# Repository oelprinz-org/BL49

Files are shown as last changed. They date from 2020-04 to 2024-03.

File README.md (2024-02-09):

# BL49

Wideband Lambda Controller with Bosch CJ125 and LSU 4.9 with 0-5V output and CAN-Bus Interface

Feature list

- CAN output, compatible with AEM X-Series UEGO
- analog output for lambda 0.65 to 1.3 (0.25v to 4.8V)
- debug messages over CAN (pid, heater status, diag registers, ...)
- activatable via TTL input (INPUT 1)
- fast: 10ms refresh rate (reading the probe, calculation lambda and O2, sending CAN message and setting analog output)
- Bosch recommended heating strategy

## 04.01.2023 - Current status of firmware development

- analog output for lambda 0.65 to 1.3 (0.25v to 4.8V): done
- CAN output (AEM X-Series UEGO protocol): done
- debug messages over CAN: done
- Bosch recommended heating strategy: done
- PID controller for heating the probe: done
- activation per GPIO (pull **IN1** to GND): done
- <del>activation per CAN: open</del>

## 29.04.2020 - Version 0.0.1 - only hardware released / no software available at the moment  

Interactive BOM for easier hand-soldering you can download from the github (BL49/hardware/V0.0.1/bom)  
or access online here: <https://oelprinz.000webhostapp.com/BL49/V0.0.1/iBOM/ibom.html>  
Quick link to schematic: <https://github.com/oelprinz-org/BL49/blob/master/hardware/V0.0.1/schematics.pdf>  

## Bosch CJ125 (LQFP32 package) part numbers

|Bosch part number|
|:----------------|
|30615|
|40103|
|30522|

### Suitable Bosch lambda probes

Basically, the Bosch probes whose numbers start with **0 258 017** will fit, also Bosch **0 281 004**.  
Bosch numbers beginning with **0 258 007** are *LSU 4.2* probes and will not fit.

|Bosch number  |Length overall|Comment|
|---|---|---|
|0 258 017 012 |1060mm||
|0 258 017 025 |1000mm|Bosch motorsport part, **tested during development**|
|0 281 004 028 |540mm|common probe for diesel engines, **Used during development**|
|0 258 017 029 |620mm|grey, used by BMW after 09/2006 (1178 7539124)|
|0 258 017 038 |340mm|grey, used by BMW (11787537984)|
|0 258 017 092 |950mm|black, used by BMW (1178 7540167)|
|0 258 017 126 |680mm|black, used by BMW after 09/2006 (1178 7561410)|
|0 281 004 150 |1215mm||
|0 281 004 184 |1000mm||
|...|||

### LSU4.9 probe pinout

|Pin#|Color|Description|Symbol|
|----|-----|---|---|
|1|red|Pump current APE|IP|
|2|yellow|Virtual ground IPN|VM|
|3|white|Heater voltage H-|Uh-|
|4|grey|Heater voltaget H+|Uh+|
|5|green|Trim Resistor RT|IA|
|6|black|Nernst voltage UN|RE|

### Hardware

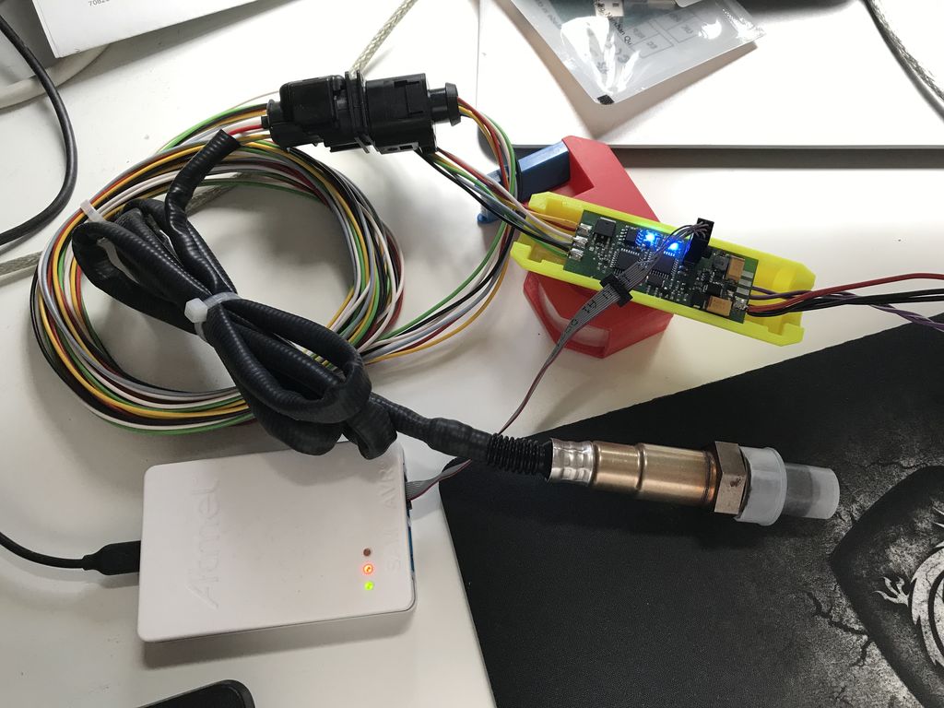
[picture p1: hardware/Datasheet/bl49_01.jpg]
Hardware


### MCU Fuses

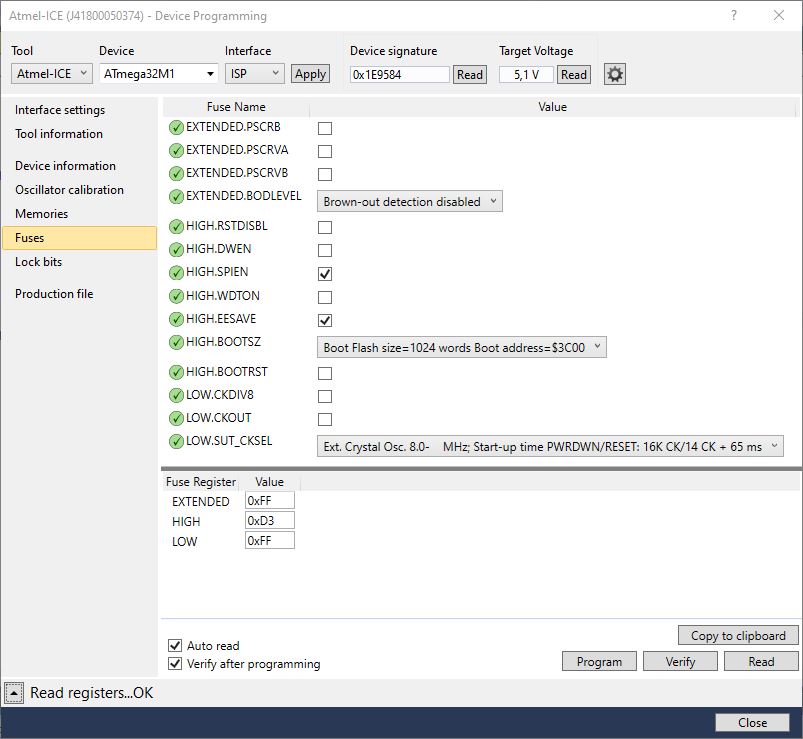
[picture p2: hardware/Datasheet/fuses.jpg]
Fuses


### AEM X-Series CAN layout

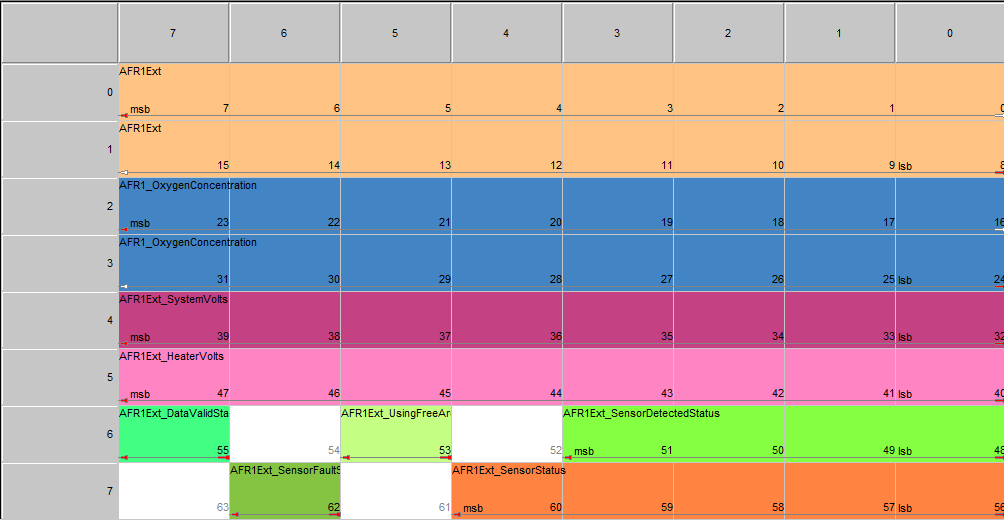
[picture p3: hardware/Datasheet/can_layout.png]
AEM X-Series CAN layout


### Assembled Prototype

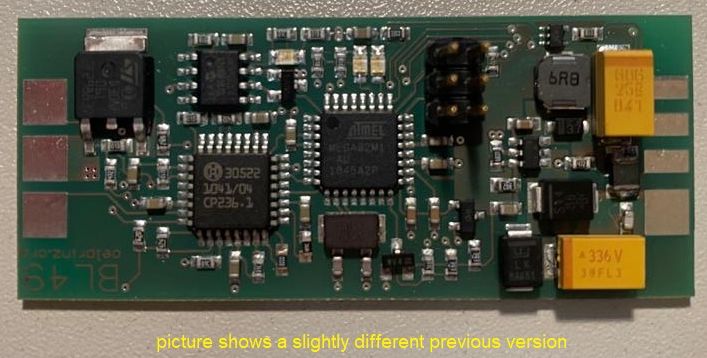
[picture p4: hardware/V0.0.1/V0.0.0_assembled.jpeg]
Assembled Prototype


### PCB Layout

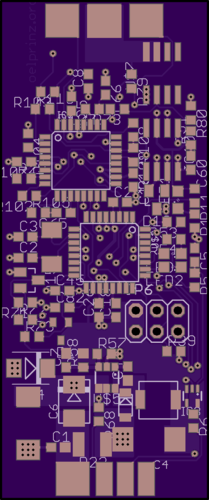
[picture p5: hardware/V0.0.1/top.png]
Top Side

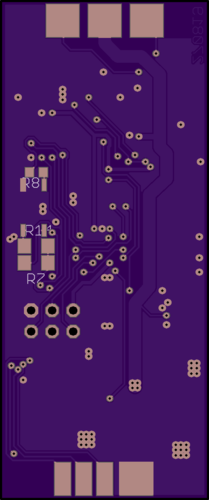
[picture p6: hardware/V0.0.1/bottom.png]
Bottom

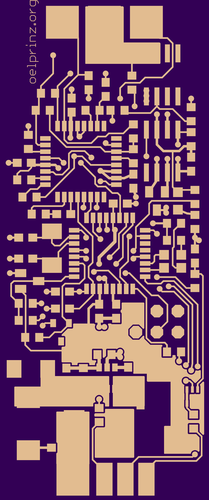
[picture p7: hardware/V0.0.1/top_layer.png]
Top Layer

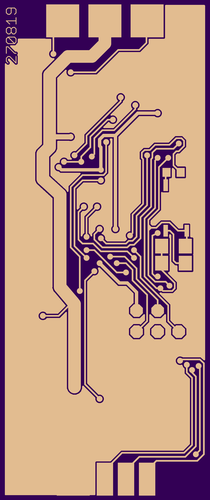
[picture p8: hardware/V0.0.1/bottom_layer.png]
Bottom Layer


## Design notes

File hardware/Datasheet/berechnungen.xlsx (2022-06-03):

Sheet: PWM
Fcpu | 16000000
Prescaler | 256 | 1, 8, 64, 256 and 1024 are valid
Resolution, bit | 8
TOP | 255
Fpwm | 244.140625
Ubat, V | 13.6
condens, V | 1.5
duty, % | 11.02941176
dutyCycle | 112.9411765

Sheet: Ip
Shunt | 61900
Amp | 8
Ua | 2069
Ua_ref | 1503
delta | 566000
divisor | 495200
Ip | 1142.972536

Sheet: ADC
Referenz, V | 5
ADC Wert | 563 | 566
ADC-Spannung, V | 2.749023438
Reihenwiderstand | 40000
Massenwiderstand | 10000
Spannungsteiler | 5 | Gesamtwiderstand / Massenwiderstand
echte Spannung, V | 13.74511719
echte Spannung, V | 13
ADC-Spannung, V | 2.6
ADC-Wert | 532.48
ADC Wert für Referenz | 247
Spannung | 1.206054688
Differenz | -0.0189453125
ADC Ua | 135 | 0.6591796875
ADC Ur | 299 | 1.459960938
Ua bereinigt | 0.678125
Ur bereinigt | 1.47890625
Spannung Referenz, mV | 1225
ADC Wert dazu: | 251 | 1225.585938
Spannung Referenz gemessen | 247
Drift: | 978
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

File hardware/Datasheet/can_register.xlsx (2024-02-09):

CANPAGE
MOBNB3 | MOBNB2 | MOBNB1 | MOBNB0 | AINC | INDX2 | INDX1 | INDX0 | HexWert
0 | 0 | 0 | 1 | 0 | 0 | 0 | 1 | 11
CANGSTA
- | OVRG | - | TXBSY | RXBSY | ENFG | BOFF | ERRP | HexWert
 | 0 |  | 0 | 0 | 0 | 0 | 0
CANSTMOB
DLCW | TXOK | RXOK | BERR | SERR | CERR | FERR | AERR | HexWert
0 | 0 | 0 | 0 | 0 | 0 | 0 | 0 | 0
CANGIT
CANIT | BOFFIT | OVRTIM | BXOK | SERG | CERG | FERG | AERG | HexWert
1 | 0 | 1 | 0 | 0 | 0 | 0 | 0 | a0
CANCDMOB
CONMOB1 | CONMOB0 | RPLV | IDE | DLC3 | DLC2 | DLC1 | DLC0 | HexWert
0 | 1 | 0 | 1 | 0 | 0 | 1 | 0 | 52

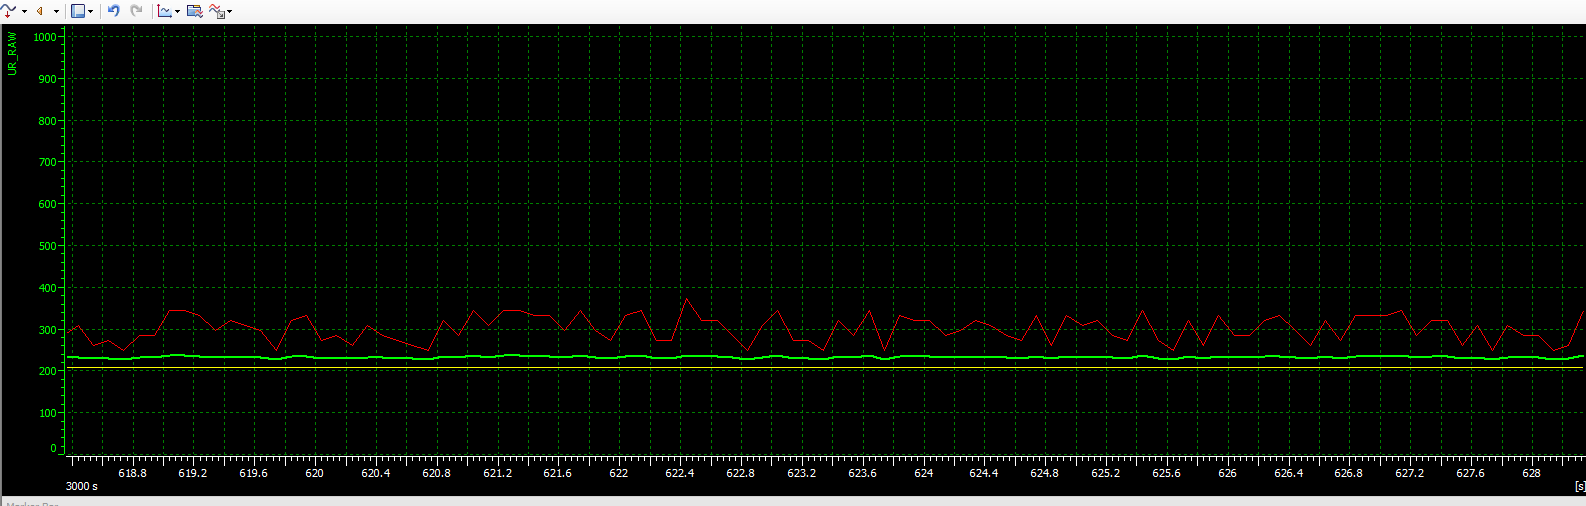
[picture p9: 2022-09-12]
hardware/Datasheet/PID.png

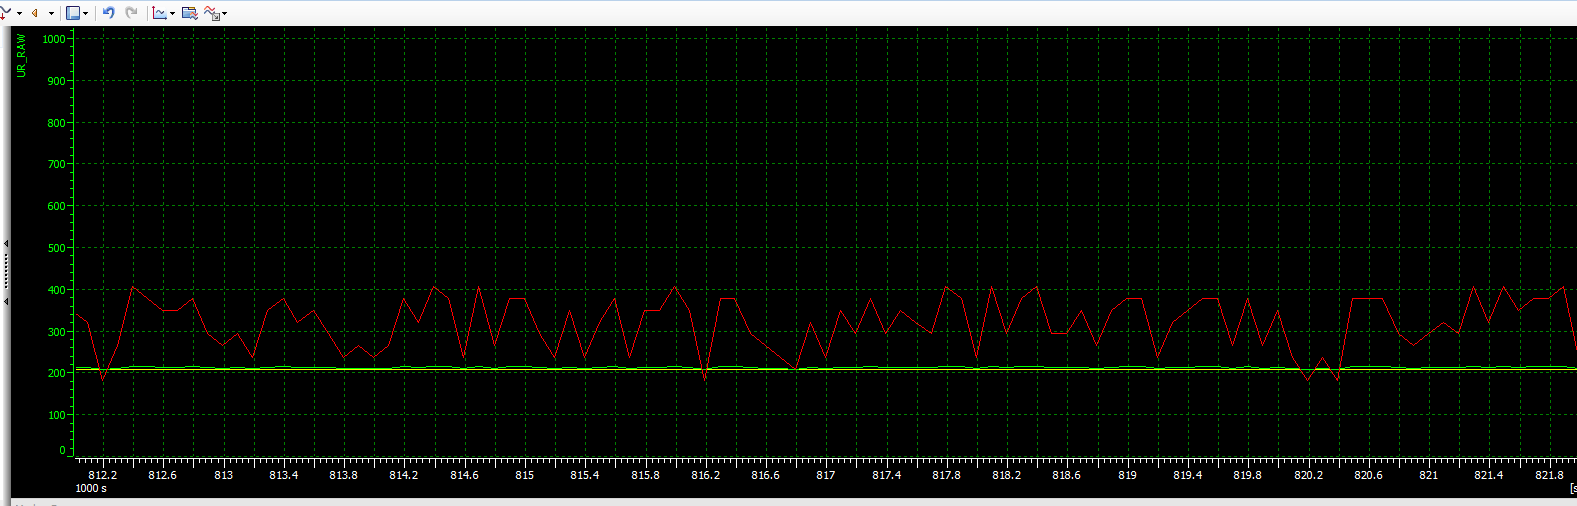
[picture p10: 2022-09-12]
hardware/Datasheet/PID_2.png

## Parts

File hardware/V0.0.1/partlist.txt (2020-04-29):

Qty Value                Device              Package       Parts                                            Description                                                              MF MPN            OC_FARNELL OC_NEWARK
3   100k                 R-EU_R0603          R0603         R80, R107, R108                                  RESISTOR, European symbol                                                                                      
10  100n                 C-EUC0603           C0603         C7, C16, C18, C22, C25, C26, C60, C65, C66, C107 CAPACITOR, European symbol                                                                                     
1   100nF                C-EUC0603           C0603         C5                                               CAPACITOR, European symbol                                                                                     
1   100r                 R-EU_R1206          R1206         R7                                               RESISTOR, European symbol                                                                                      
4   10k                  R-EU_R0603          R0603         R11, R29, R71, R104                              RESISTOR, European symbol                                                                                      
1   120r                 R-EU_R1206          R1206         R14                                              RESISTOR, European symbol                                                                                      
1   1235AS-H-6R8M        1235AS-H-6R8M       1235AS-H-6R8M L4                                                                                                                                                              
1   15n                  C-EUC0603           C0603         C46                                              CAPACITOR, European symbol                                                                                     
2   18p                  C-EUC0603           C0603         C2, C3                                           CAPACITOR, European symbol                                                                                     
5   1k                   R-EU_R0603          R0603         R1, R6, R53, R54, R91                            RESISTOR, European symbol                                                                                      
1   1n                   C-EUC0603           C0603         C1                                               CAPACITOR, European symbol                                                                                     
1   2n2                  C-EUC0603           C0603         C8                                               CAPACITOR, European symbol                                                                                     
1   300/1%               R-EU_R0603          R0603         R102                                             RESISTOR, European symbol                                                                                      
1   31k6/1%              R-EU_R0603          R0603         R105                                             RESISTOR, European symbol                                                                                      
1   33k                  R-EU_R0603          R0603         R5                                               RESISTOR, European symbol                                                                                      
2   33n                  C-EUC0603           C0603         C45, C82                                         CAPACITOR, European symbol                                                                                     
2   39k                  R-EU_R0603          R0603         R72, R73                                         RESISTOR, European symbol                                                                                      
1   3k9                  R-EU_R0603          R0603         R58                                              RESISTOR, European symbol                                                                                      
1   470k                 R-EU_R0603          R0603         R110                                             RESISTOR, European symbol                                                                                      
5   4k7                  R-EU_R0603          R0603         R8, R39, R68, R78, R109                          RESISTOR, European symbol                                                                                      
1   61R9                 R-EU_R0603          R0603         R103                                             RESISTOR, European symbol                                                                                      
1   680r                 R-EU_R0603          R0603         R57                                              RESISTOR, European symbol                                                                                      
1   6k8                  R-EU_R0603          R0603         R79                                              RESISTOR, European symbol                                                                                      
1   ABM3-16.000MHZ-D2Y-T ABM3-8.000MHZ-D2Y-T ABM3          Q3                                                                                                                                                              
1   ATMEGA32M1-AU        AT32M1              TQFP32-08     U$2                                                                                                                                                             
1   B72530V1140S262      VARISTORCN1210      CT/CN1210     R23                                              VARISTOR                                                                                                       
1   BAT54S               BAT54S              SOT23         D15                                              Schottky Diodes                                                                                                
1   BD9G101G             BD9G101G            SSOT6         U$5                                                                                                                                                             
1   BL49                 BL49                BL49          U$1                                                                                                                                                             
1   CJ125_32             CJ125_32            TQFP32-08     IC9                                                                                                                                                             
1   CPC1017N             CPC1017N            CPC1017N      U$4                                                                                                                                                             
1   ISP(NC)              PINHD-2X3           2X03          JP6                                              PIN HEADER                                                                                                     
1   LM4041DIM3-1.2       LM4041A12DBZ        DBZ_R-PDSO-G3 D1                                               PRECISION MICROPOWER SHUNT VOLTAGE REFERENCE                                LM4041A12IDBZR 1407949    58K5875  
1   LMV321IDBVR          LMV321M7            SC70-5L       IC3                                              General Purpose, Low Voltage, Rail-to-Rail Output Operational Amplifiers                                       
1   MCP2551-E/SN         MCP255              SOIC8         IC10                                                                                                                                                            
1   PESD1CAN             PESD1CAN            SOT23         D10                                              CAN bus ESD protection diode                                                                                   
1   RB060MM-60           RB060MM-60          RB060MM-60    D5                                                                                                                                                              
1   SMBJ22A              SUPPRESSOR-SMBJ     SMBJ          D4                                               Suppressor diode                                                                                               
1   SSB44-E3/52T         MURS120             MURS120       D2                                                                                                                                                              
1   TAJD336*035#NJ       CPOL-EUSMCD         SMC_D         C6                                               POLARIZED CAPACITOR, European symbol                                                                           
1   TAJD686*025#NJ       CPOL-EUSMCD         SMC_D         C4                                               POLARIZED CAPACITOR, European symbol                                                                           
1   VNS3NV04DP           VNS3NV04DP          SO8           U$7                                                                                                                                                             
3   blau                 LEDSML0805          SML0805       LED1, LED2, LED3                                 LED

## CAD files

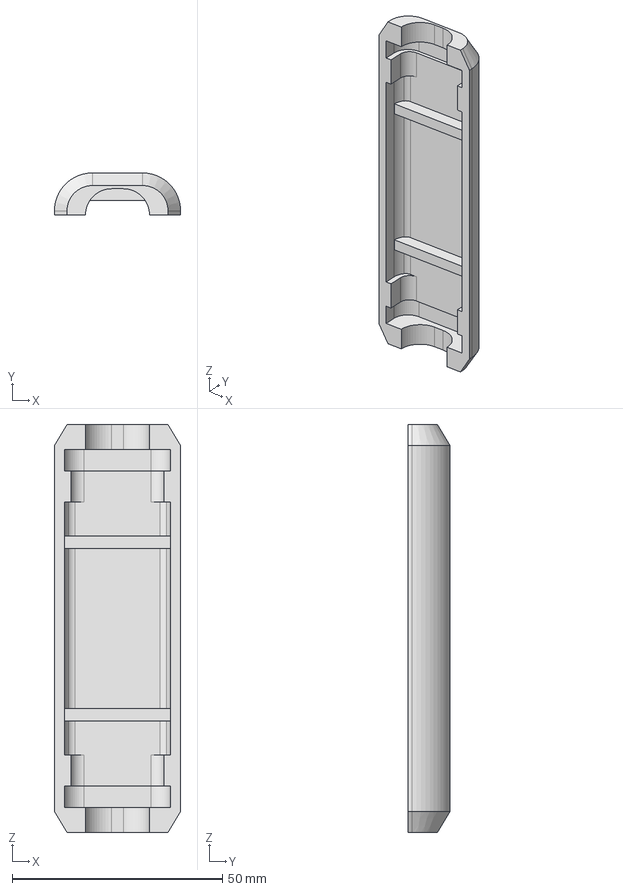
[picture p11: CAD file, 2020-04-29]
hardware/case/case_bl49.stp
30.0 x 10.0 x 97.0 mm

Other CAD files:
hardware/case/case_bl49.stl

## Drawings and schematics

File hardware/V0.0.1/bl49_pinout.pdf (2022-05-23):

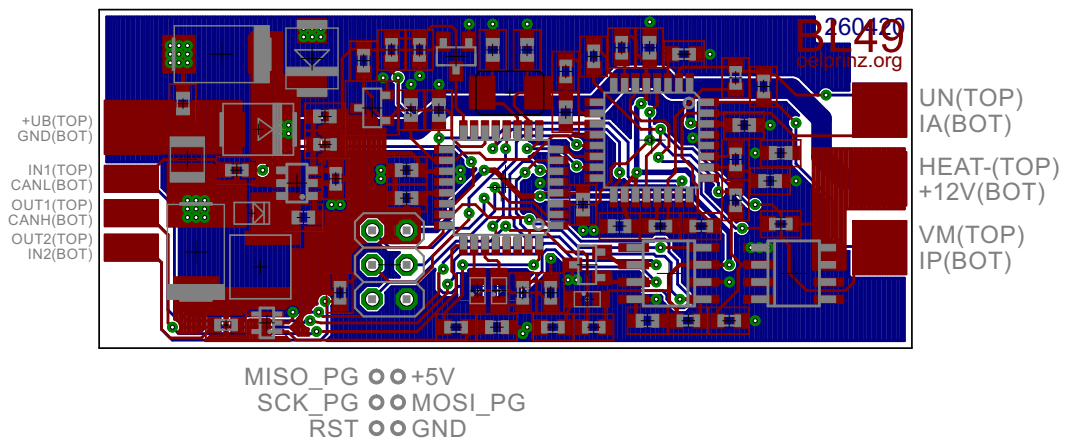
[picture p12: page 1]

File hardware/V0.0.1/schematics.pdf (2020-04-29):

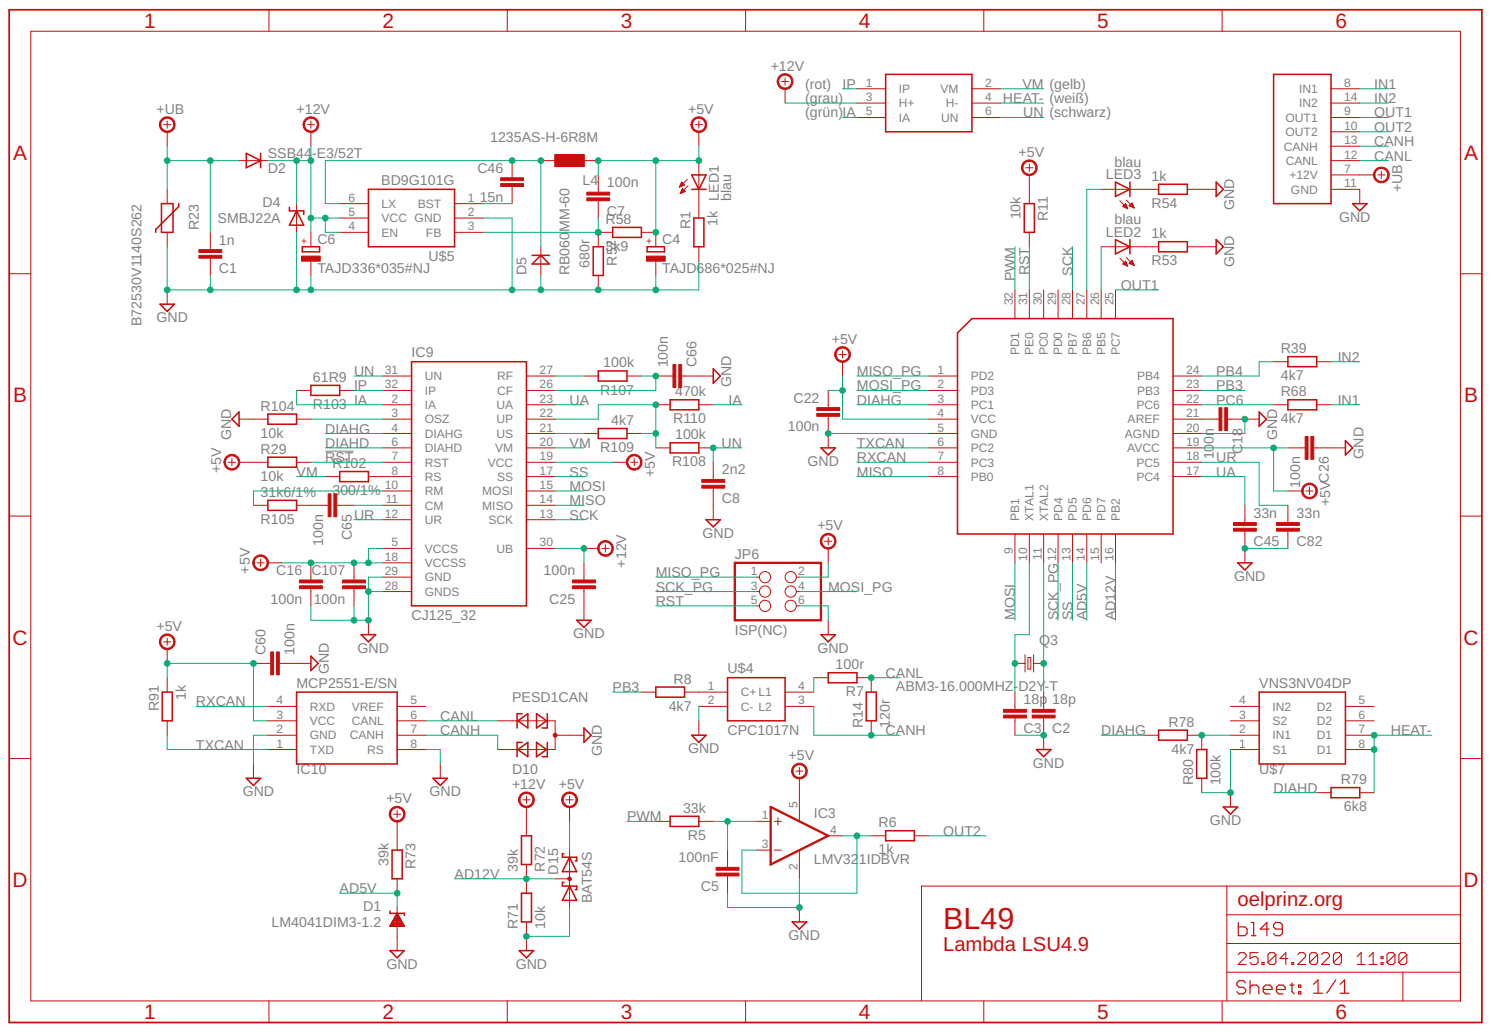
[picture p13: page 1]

UR | | 13 MISO SCK

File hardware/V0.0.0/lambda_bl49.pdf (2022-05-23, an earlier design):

A

A

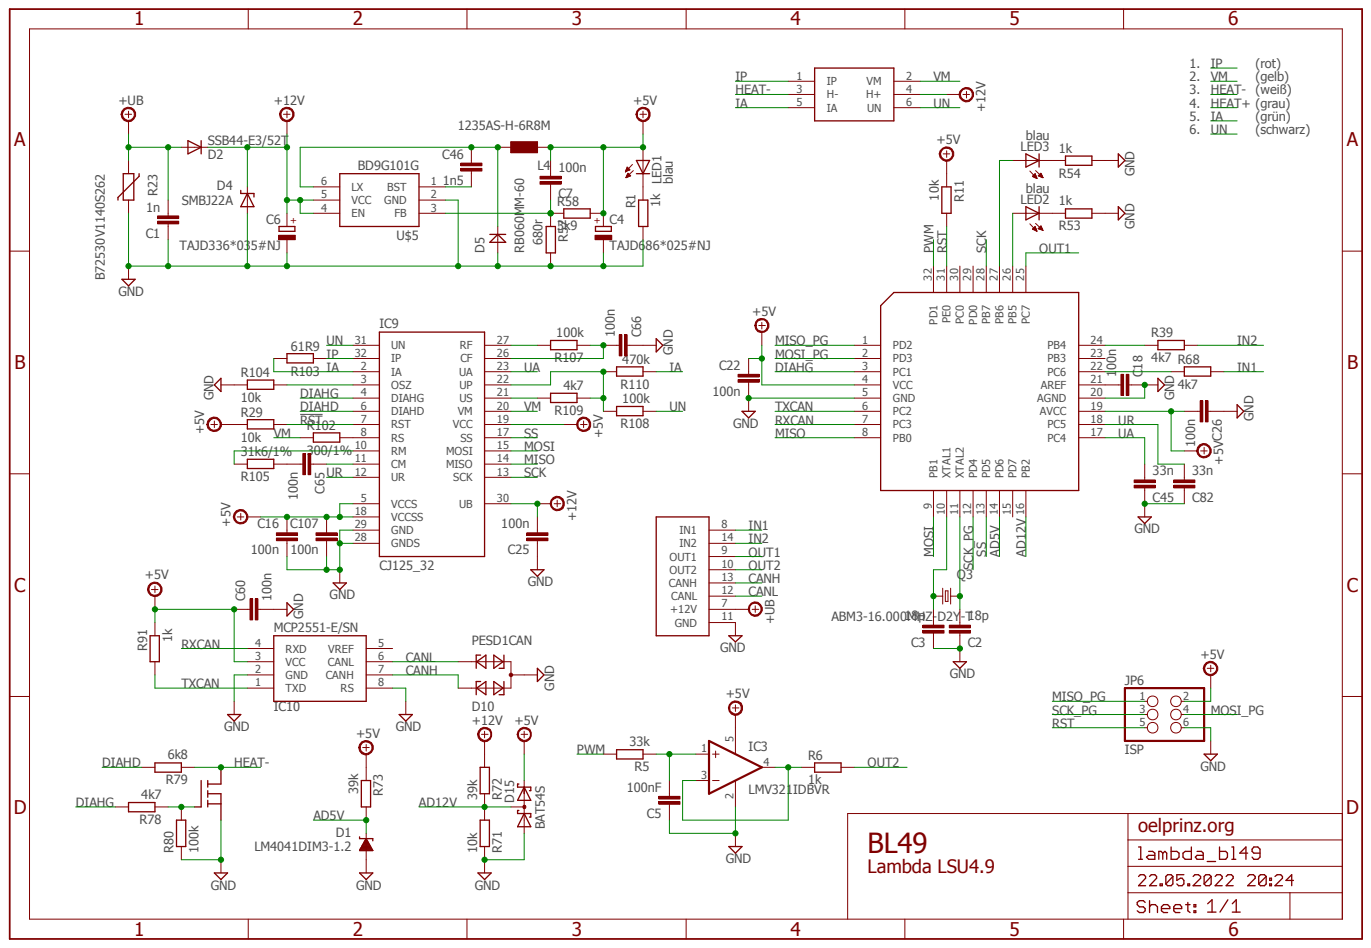
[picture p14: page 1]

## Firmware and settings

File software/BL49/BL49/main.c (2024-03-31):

/*
 * BL49.c
 *
 * Created: 22.05.2022 20:35:45
 * Author : Heinrich
 */ 

#include <avr/io.h>
#include <avr/interrupt.h>

#include "helpers.h"
#include "adc/adc.h"
#include "spi/spi.h"
#include "dac/dac.h"
#include "cj125/cj125.h"
#include "timer/timer.h"
#include "sensor/sensor.h"
#include "board/board.h"
#include "can/can_network.h"

extern tSensor sensor1;
extern tBoard board;
extern volatile uint16_t ms_counter;

int main(void)
{
	uint8_t counter = 0;
	uint16_t adcValue = 0;
	uint16_t pid = 0;
	tcj125_command_status commStatus;

	adc_init();
	spi_init();
	dac_init();
	can_network_init(1);

	board_init(&board);	
	sensor_init(&sensor1, 8);
	board_read_inputs(&board);
	
	timer_delay_ms(100);
	
	sei();

	commStatus = cj125_set_calibration_mode();
	
	
	timer_delay_ms(100);
	
	// commStatus = cj125_read_init1_register(&registerData);
	
	
	// Ur value: lower value means hotter sensor...
	// Ur_ref is something round about 1v (ADC 208 = 1015mV)
	// Ua_ref is something round about 1.5v (ADC 309 =  1503mV)
	
	sensor1.Ur_ref_raw = adc_read_UR();
	sensor1.Ur_ref = adc2voltage_millis(sensor1.Ur_ref_raw);
	sensor1.Ua_ref = adc2voltage_millis(adc_read_UA());

	cj125_set_running_mode_v8();
	timer_delay_ms(100);

	sensor_update_status();
	
	init_1ms_timer();
	
	while(1)
	{
		if (bit_check(TIMER_TASKS, BIT_TIMER_10ms))
		{
			bit_clear(TIMER_TASKS, BIT_TIMER_10ms);
			
			if (sensor1.SensorStatus == RUN && sensor1.SystemVoltageOK == true && sensor1.SensorFaultState == OK)
			{
				sensor_update_ua(&sensor1, adc2voltage_millis(adc_read_UA()));
				dac_update_output(sensor1.Lambda);
			}
			
			can_send_aem_message(sensor1);
		}
		
		if (bit_check(TIMER_TASKS, BIT_TIMER_100ms))
		{
			bit_clear(TIMER_TASKS, BIT_TIMER_100ms);
			sensor_update_status();
			
			// is sensor activated? Transition from RESET (inactive) to start up
			if (isActive() && sensor1.SensorStatus == RESET)
			{
				// set sensor to evap_start_up...
				// from now is heater active and starting up
				// first of all, some time (2s are enough) for evaporation (heater = 1,5v)
				sensor1.SensorStatus = EVAP_START_UP;
				heater_setVoltage(1500);
				counter = 0;
				led1_setState(ON);
			} 
			else if (isActive() && sensor1.SensorStatus == EVAP_START_UP)
			{
				// sensor is in evaporation state, so just check counter 
				counter++;
				
				// if time is over, switch status to next status, WARMING UP
				// set heater to 8.5v
				if (counter == 20)
				{
					sensor1.SensorStatus = WARMING_UP;
					heater_setVoltage(8500);
				}
			}
			
			// transition from non-reset (i.e. warming up, evaporation, run, ...) to dactivated:
			else if (!isActive() && sensor1.SensorStatus != RESET)
			{
				sensor_shutdown();
				dac_setValue(0);
				led1_setState(OFF);
			}
			
			else if (!isActive())
			{
				led2_toggle();

			}
		}
		
		if (bit_check(TIMER_TASKS, BIT_TIMER_250ms))
		{
			bit_clear(TIMER_TASKS, BIT_TIMER_250ms);
			
			can_send_debug_message(sensor1.Ur_ref_raw, adcValue, pid, sensor1.Signature, sensor1.diagRegister);
			
			if (isActive() && sensor1.SensorStatus == WARMING_UP && sensor1.SystemVoltageOK && sensor1.SensorFaultState == OK)
			{
				// increase heater voltage
				sensor1.HeaterVoltage += 100;
				
				// heater voltage is 13v, warming up is completed, next status is RUN
				if (sensor1.HeaterVoltage > 13000)
				{
					sensor1.HeaterVoltage = 13000;
					sensor1.SensorStatus = RUN;
				}
				heater_setVoltage(sensor1.HeaterVoltage);
				led2_toggle();
			}
			
			// we are in a running state, just adjust PID and heater
			else if (isActive() && sensor1.SensorStatus == RUN)
			{
				adcValue = adc_read_UR();
				pid = calc_pid(sensor1.Ur_ref_raw, adcValue, true);
				heater_setVoltage(duty_cycle2voltage(sensor1.SystemVoltage, pid, 256));
				sensor1.Ur = adc2voltage_millis(adcValue);
			}
		}
		
		if (bit_check(TIMER_TASKS, BIT_TIMER_500ms))
		{
			bit_clear(TIMER_TASKS, BIT_TIMER_500ms);
			if (isActive() && sensor1.SensorStatus == RUN)
			{
				led2_toggle();
			}
		}
	}
}

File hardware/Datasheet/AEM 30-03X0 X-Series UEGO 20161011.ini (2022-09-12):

[View_Vehicles]
HIDDEN=
ORDER=0,1,
DEFINITIONS=
COLUMNWIDTHS=125,150,
[View_Vehicle]
HIDDEN=
ORDER=0,1,
DEFINITIONS=
COLUMNWIDTHS=125,125,
[View_VehicleNetworks]
HIDDEN=3,
ORDER=0,1,2,3,4,5,6,7,8,9,10,
DEFINITIONS=6,7,8,9,10,11,12,
COLUMNWIDTHS=125,125,100,100,150,100,100,50,50,50,50,100,
[View_VehicleNetwork]
HIDDEN=
ORDER=0,1,2,3,4,5,6,
DEFINITIONS=4,5,
COLUMNWIDTHS=125,125,100,125,150,50,100,
[View_VehicleNetworkTxMessages]
HIDDEN=
ORDER=0,1,2,3,4,5,6,7,8,9,10,11,12,
DEFINITIONS=1,2,3,13,
COLUMNWIDTHS=125,125,55,100,50,100,100,100,150,50,100,100,100,
[View_VehicleNetworkSignals]
HIDDEN=
ORDER=0,1,2,3,4,5,6,7,8,9,10,11,12,13,14,15,
DEFINITIONS=
COLUMNWIDTHS=125,125,100,50,100,50,100,100,100,50,50,50,50,100,100,150,
[View_VehicleControlUnit]
HIDDEN=
ORDER=0,1,2,3,4,5,6,
DEFINITIONS=4,5,
COLUMNWIDTHS=125,125,100,125,150,50,100,
[View_VehicleGateways]
HIDDEN=
ORDER=0,1,2,
DEFINITIONS=
COLUMNWIDTHS=125,125,100,
[View_VehicleGatewaySignals]
HIDDEN=
ORDER=0,1,2,3,4,5,6,
DEFINITIONS=
COLUMNWIDTHS=125,125,125,125,125,125,125,
[View_Networks]
HIDDEN=2,
ORDER=0,1,2,3,4,5,6,7,8,9,
DEFINITIONS=6,7,8,9,10,11,12,
COLUMNWIDTHS=125,100,100,150,100,100,50,50,50,50,100,
[View_Network]
HIDDEN=
ORDER=0,1,2,3,4,5,
DEFINITIONS=4,5,
COLUMNWIDTHS=125,125,100,150,50,100,
[View_NetworkTxMessages]
HIDDEN=
ORDER=0,1,2,3,4,5,6,7,8,9,10,11,12,
DEFINITIONS=1,2,3,13,
COLUMNWIDTHS=125,125,55,100,50,100,100,100,150,50,100,100,100,
[View_NetworkTxSignals]
HIDDEN=
ORDER=0,1,2,3,4,5,6,7,8,9,10,11,12,13,14,15,
DEFINITIONS=
COLUMNWIDTHS=125,125,100,50,100,50,100,100,100,50,50,50,50,100,100,150,
[View_NetworkNodeGroup]
HIDDEN=
ORDER=0,1,2,3,4,
DEFINITIONS=4,5,
COLUMNWIDTHS=125,100,150,50,100,
[View_Ecus]
HIDDEN=
ORDER=0,1,
DEFINITIONS=
COLUMNWIDTHS=125,150,
[View_Ecu]
HIDDEN=
ORDER=0,1,2,3,4,5,
DEFINITIONS=4,5,
COLUMNWIDTHS=125,125,100,150,50,100,
[View_EnvVars]
HIDDEN=
ORDER=0,1,2,3,4,5,6,7,8,9,
DEFINITIONS=
COLUMNWIDTHS=125,100,100,50,50,50,50,100,100,150,
[View_EnvVar]
HIDDEN=
ORDER=0,1,2,3,4,5,6,7,8,9,10,
DEFINITIONS=
COLUMNWIDTHS=125,125,100,100,50,50,50,50,100,100,150,
[View_NodeGroups]
HIDDEN=
ORDER=0,1,
DEFINITIONS=
COLUMNWIDTHS=125,150,
[View_NodeGroup]
HIDDEN=
ORDER=0,1,2,3,
DEFINITIONS=
COLUMNWIDTHS=125,125,55,150,
[View_Nodes]
HIDDEN=
ORDER=0,1,2,3,4,
DEFINITIONS=4,5,
COLUMNWIDTHS=125,100,150,50,100,
[View_Node]
HIDDEN=
ORDER=0,1,2,3,4,5,6,7,8,9,10,11,12,13,14,
DEFINITIONS=
COLUMNWIDTHS=125,125,100,50,50,100,100,100,50,50,50,50,100,100,150,
[View_NodeTxMessages]
HIDDEN=
ORDER=0,1,2,3,4,5,6,7,8,9,10,11,
DEFINITIONS=1,2,3,13,
COLUMNWIDTHS=125,125,55,100,50,100,100,150,50,100,100,100,
[View_NodeTxMsg]
HIDDEN=
ORDER=0,1,2,3,4,5,6,7,8,9,10,11,12,13,14,
DEFINITIONS=
COLUMNWIDTHS=125,125,100,50,50,100,100,100,50,50,50,50,100,100,150,
[View_NodeTxSignals]
HIDDEN=
ORDER=0,1,2,3,4,5,6,7,8,9,10,11,12,13,14,
DEFINITIONS=
COLUMNWIDTHS=125,125,100,50,50,100,100,100,50,50,50,50,100,100,150,
[View_NodeRxSignals]
HIDDEN=
ORDER=0,1,2,3,4,5,6,7,8,9,10,11,12,13,14,
DEFINITIONS=
COLUMNWIDTHS=125,125,100,50,50,100,100,100,50,50,50,50,100,100,150,
[View_NodeTxSigs]
HIDDEN=
ORDER=0,1,2,3,4,5,6,7,8,9,10,11,12,
DEFINITIONS=
COLUMNWIDTHS=125,125,50,100,100,100,50,50,50,50,100,100,150,
[View_NodeRxSigs]
HIDDEN=
ORDER=0,1,2,3,4,5,6,7,8,9,10,11,12,
DEFINITIONS=
COLUMNWIDTHS=125,125,50,100,100,100,50,50,50,50,100,100,150,
[View_Messages]
HIDDEN=
ORDER=0,1,2,3,4,5,6,7,8,9,10,11,
DEFINITIONS=1,2,3,13,
COLUMNWIDTHS=125,55,100,50,100,100,100,150,50,100,100,100,
[View_Message]
HIDDEN=
ORDER=0,1,2,3,4,5,6,7,8,9,10,11,12,13,14,
DEFINITIONS=
COLUMNWIDTHS=206,125,100,50,50,100,100,100,50,50,50,50,100,100,150,
[View_Signals]
HIDDEN=
ORDER=0,1,2,3,4,5,6,7,8,9,10,11,
DEFINITIONS=
COLUMNWIDTHS=125,50,100,100,100,50,50,50,50,100,100,150,
[View_ValueTables]
HIDDEN=
ORDER=0,1,
DEFINITIONS=
COLUMNWIDTHS=125,150,
[View_AttrDefs]
HIDDEN=6,
ORDER=0,1,2,3,4,5,
DEFINITIONS=
COLUMNWIDTHS=125,100,100,50,50,100,150,

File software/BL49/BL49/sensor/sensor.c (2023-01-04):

/*
 * sensor.c
 *
 * Created: 23.05.2022 15:12:39
 *  Author: Heinrich
 */ 

#include "sensor.h"
#include "../board/board.h"
#include "../helpers.h"

// pump current and lambda values from Bosch datasheet
// Ip * 1000
// lambda * 1000
int16_t ip_values[] = {-2000, -1602, -1243, -927, -800, -652, -405, -183, -106, -40, 0, 15, 97, 193, 250, 329, 671, 938, 1150, 1385, 1700, 2000, 2150, 2250};
uint16_t lambda_values[] = {650, 700, 750, 800, 822, 850, 900, 950, 970, 990, 1003, 1010, 1050, 1100, 1132, 1179, 1429, 1701, 1990, 2434, 3413, 5391, 7506, 10119};
	
// pump current corresponding to O2 concentration
// ip_values_o2 * 1000
// o2_values_percent * 1000, ready to transfer per CAN
int16_t ip_values_o2[] = {0, 330, 670, 940, 1380, 2540};
uint16_t o2_values_percent[] = {0, 3000, 6000, 8290, 12000, 20950};

tPIDController pidController;
tSensor sensor1;
extern tBoard board;

void sensor_init (tSensor *sensor, uint8_t amplification_factor)
{
	sensor->SensorStatus = RESET;
	sensor->SensorFaultState = OK;
	sensor->Shunt = 61900;
	sensor->Ip = 0;
	sensor->Lambda = 0;
	sensor->Ua = 0;
	sensor->Ua_ref = 0;
	sensor->Ur = 0;
	sensor->O2 = 0;
	sensor->HeaterVoltage = 0;
	sensor->diagRegister = 0;
	sensor->SensorDetectedStatus = BOSCH_LSU49;
	sensor->Amplification = amplification_factor;
	
	cj125_readSignature(&sensor->Signature);
	
	heater_init();
}

void heater_init (void)
{
	// init COM1B1 as GPIO (PC1) and default low:
	// if bit COM1B1 is 0, then pc1 acts as gpio with original state (so, output and low)
	DDRC |= (1 << PINC1);		// PC1 is an output
	PORTC &= ~(1 << PINC1);	// and is low
	
	// pin pc1 (OC1B, Timer 1 output compare B) connected to sensor heater
	// fast pwm mode, prescaler 64,  top 0x03ff (1023) = 244Hz
	// pwm mode 7, 10-bit resolution
	// clear oc1b on compare match
	// TCCR1A |= (1 << WGM11)|(1 << WGM10)|(1 << COM1B1);
	// TCCR1B |= (1 << WGM12)|(1 << CS11)|(1 << CS10);
	
	// pin pc1 (OC1B, Timer 1 output compare B) connected to sensor heater
	// fast pwm mode, prescaler 256,  top 0x0ff (255) = 244Hz
	// pwm mode 5, 8-bit resolution
	// clear oc1b on compare match
	TCCR1A |= (1 << WGM10)|(1 << COM1B1);
	TCCR1B |= (1 << WGM12)|(1 << CS12);
	
	// init pid controller...
	// original values: p = 120; i = 0.8; d = 10;
	// optimal values seems to be p=7.1, i=0.3, d=0
	
	pidController.pGain = 5;
	pidController.iGain = 0.8;
	pidController.dGain = 3.2;
	
	pidController.iMin = -250;
	pidController.iMax = 250;
	pidController.pwmMin = 0;
	pidController.pwmMax = 240;
		
	heater_setDuty(0);
}

void sensor_update_status (void)
{	
	sensor1.SystemVoltage = adc2voltage_millis(adc_read_battery()) * 5;
	
	sensor1.SystemVoltageOK = is_between(sensor1.SystemVoltage, 11000, 16500) ? true : false;
	
	if (cj125_readStatus(&sensor1.diagRegister) == COMMAND_VALID)
	{

		// check that everythingis okay...
		if (sensor1.diagRegister == CJ125_DIAG_REG_STATUS_OK)
		{
			sensor1.SensorFaultState = OK;
		}
		else
		{	
			sensor1.SensorFaultState = FAULT;
			// if not, check what's wrong.
			// check the heater
			switch ((sensor1.diagRegister >> 6)&CJ125_DIAG_MASK)
			{
				case 0:
				case 2:
					sensor1.SensorStatus = HEATER_SHORT_CIRCUIT;
					break;
				
				case 1:
					sensor1.SensorStatus = HEATER_OPEN_CIRCUIT;
					break;
			}
		}
	}
	else
	{
		sensor1.SensorStatus = ERROR;
		sensor1.SensorFaultState = FAULT;
	}
}

int16_t calculate_ip (uint16_t Ua_ref, uint16_t Ua, uint8_t amp)
{
	int16_t ip;
	int32_t delta;
	int32_t divisor;
	// pump current calculation formula: Ip = (((Ua - Ua_ref) * PUMP_FACTOR ) / (SENSOR_SHUT * AMPLIFICATION)) * 1000
	delta = ((int32_t)Ua - (int32_t)Ua_ref) * 1000;
	// divisor = (int32_t)SENSOR_SHUNT * (int32_t)amp;	
	divisor = (int32_t)sensor1.Shunt * (int32_t)amp;	
	ip = (int16_t)(((float)delta / (float)divisor)*1000);
	return ip;
}

uint16_t calculate_lambda (int16_t Ip)
{
	uint8_t counter = 0;
	uint16_t Lambda = 0;
	
	float gain, offset;
	
	// check against the both ends
	if (Ip <= ip_values[0])
	{
		Lambda = lambda_values[0];
	}
	
	if (Ip >= ip_values[22])
	{
		Lambda = lambda_values[22];
	}
	
	while ((Lambda == 0) && (counter < 22))
	{
		// exists an exact value?
		if ( ip_values[counter] == Ip)
		{
			Lambda = lambda_values[counter];
		}
		
		// ip value is between two values
		else if ((ip_values[counter] <= Ip) && (Ip <= ip_values[counter + 1]))
		{
			gain = (float) (lambda_values[counter+1] - lambda_values[counter]) / (ip_values[counter + 1] -  ip_values[counter]);
			
			offset = (lambda_values[counter+1] - (ip_values[counter + 1] * gain));
			
			Lambda = (uint16_t) ((Ip * gain) + offset);
		}
		counter++;
	}
	
	if (Lambda > 6600)
	{
		Lambda = 6553;
	}
	
	return Lambda;
}

uint16_t calculate_o2(int16_t Ip)
{
	uint8_t counter = 0;
	uint16_t o2 = 0;

	float gain, offset;

	// check against the both ends
	if (Ip <= ip_values_o2[0])
	{
		return o2_values_percent[0];
	}

	if (Ip >= ip_values_o2[5])
	{
		return o2_values_percent[5];
	}

	while ((o2 == 0) && (counter < 5))
	{
		// exists an exact value?
		if (ip_values_o2[counter] == Ip)
		{
			o2 = o2_values_percent[counter];
		}

		// ip value is between two values
		else if ((ip_values_o2[counter] <= Ip) && (Ip <= ip_values_o2[counter + 1]))
		{
			gain = (float)(o2_values_percent[counter + 1] - o2_values_percent[counter]) / (ip_values_o2[counter + 1] - ip_values_o2[counter]);

			offset = (o2_values_percent[counter + 1] - (ip_values_o2[counter + 1] * gain));

			o2 = (uint16_t)((Ip * gain) + offset);
		}
		counter++;
	}
	return o2;
}

void sensor_update_ua (tSensor *sensor, uint16_t ua_millis)
{
	sensor->Ua = ua_millis;
	sensor->Ip = calculate_ip (sensor->Ua_ref, sensor->Ua, sensor->Amplification);
	sensor->Lambda = calculate_lambda(sensor->Ip);
	sensor->O2 = calculate_o2(sensor->Ip);
}

void sensor_update_ur (tSensor *sensor, uint16_t ur_millis)
{
	sensor->Ur = ur_millis;
}

void heater_setVoltage (uint16_t voltageMillis)
{
	uint16_t duty = 0;
	sensor1.HeaterVoltage = voltageMillis;
	
	if (voltageMillis == 0)
	{
		heater_setDuty(0);
	}
	else
	{
		duty = voltage2duty_cycle (voltageMillis, sensor1.SystemVoltage, 256);
		heater_setDuty(duty);	
	}
}

void heater_setDuty (uint16_t duty)
{
	if (duty == 0)
	{
		TCCR1A &= ~(1 << COM1B1);
	}
	else
	{
		OCR1B = duty;
		if (!(TCCR1A |= (1 << COM1B1)))
		{
			TCCR1A |= (1 << COM1B1);
		}
	}
}
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

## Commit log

2022-05-22 added schematic and pinout of my version bl49
2022-05-24 corrected and testet dac stuff (calculation dac values for given lambda value) added state machine (timer with 10ms, 20ms, 50ms, 100ms and 250ms)
    [berechnungen.xlsx]
2022-05-29 some changes and corrections
    [berechnungen.xlsx]
2022-06-01 can stuff implemented, sensor and heater handling corrected and improved, ....
    [berechnungen.xlsx]
2022-09-07 functioning software, without PID
2022-09-07 functioning software, PID implemented but the behaviour is strange
2022-09-08 working on pid
2022-09-09 PID Settings adjusted some small changes on board and sensor increased optimal heater temperature ( ADC 208 to 96)
2022-09-14 fixed reading Ur in calibration mode...
    [board.c, cj125.c, main.c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]
2022-09-19 adc reference involved into calculation of adc values now, dac parameters checked
2023-03-25 can enable interrupt register name changed
2023-03-27 can registers added
    [can_register.xlsx]
2024-02-04 some small changes
    [can_register.xlsx]
2024-03-31 -> led hadling added: --> led1 is on when input1 is low (activated) and switch off by deactivating --> led2 is flashing with 100ms when waiting for activation --> led2 is flashing with 250ms when sta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
